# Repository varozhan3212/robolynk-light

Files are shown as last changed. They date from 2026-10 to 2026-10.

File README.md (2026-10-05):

# RoboLynk Light — a talking desk companion on an ESP32-S3

A palm-sized desk robot you hold to talk to. Press the screen, ask a question,
let go — it answers out loud, shows an animated face while it speaks, and can set
alarms and timers or control your smart lights. Everything runs on one
ESP32-S3 board with a 2.8" colour screen, and it updates itself over Wi-Fi.

It is built from an off-the-shelf dev board, so you can reproduce it without a
soldering iron: about ten minutes of hands-on work, plus an hour and twenty
minutes of printing you can leave running.

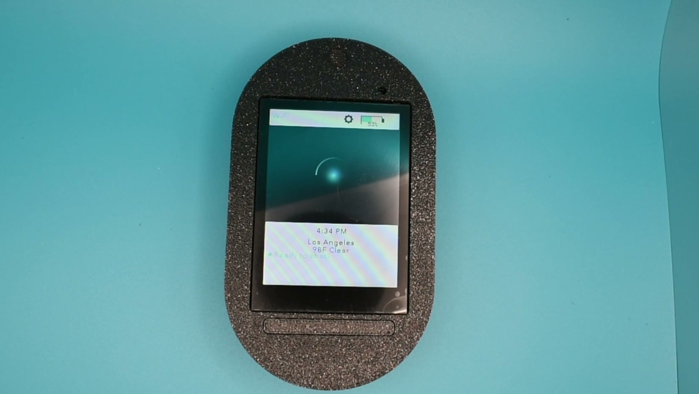
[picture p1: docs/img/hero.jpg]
RoboLynk Lite, assembled and running


---

## What it does

- **Hold-to-talk voice chat.** Press and hold the screen, speak, release. It
  remembers the last six messages, so follow-up questions work.
- **Animated face** while it speaks, drawn from frames held in RAM.
- **Alarms and timers** by voice or from the settings screen.
- **Philips Hue control** — "turn on the lights", "dim the bedroom",
  "lights to 50%".
- **Wi-Fi setup from your phone.** The robot raises its own hotspot and serves a
  small page; you type your network details there. No keyboard needed.
- **Updates itself.** On boot it checks for new firmware and installs it.
- **A light and an SOS signal, both without a network.** Tap the top-left of the
  screen to switch the built-in white LED on and off. Hold it for three seconds and
  it flashes an SOS pattern with an emergency screen. Neither needs Wi-Fi or a
  server, so they work anywhere.
- Optional GPS module for "where am I", and Bluetooth LE scanning. Without a module
  fitted, GPS simply does not appear.

Reminders and alarms here are a convenience feature. Do not rely on them for
anything that matters medically.

**▶ Watch the full build and setup (5 min):** https://youtu.be/vgklh-3mNh4

**📄 Written build guide on Hackster:**
https://www.hackster.io/varozhan/a-talking-desk-robot-you-flash-from-a-web-page-ce6271

Flashing from the browser, Wi-Fi setup from a phone, creating the account,
first boot, and the robot answering a question — start to finish, nothing cut.

---

## Parts

| Part | Notes |
|---|---|
| ES3C28P (or ES3N28P) ESP32-S3 board | [Example on Amazon](https://www.amazon.com/dp/B0FSQLPQ6M) &middot; 2.8" 240×320 ILI9341 display, capacitive touch, ES8311 audio codec, speaker amp, microSD slot, USB-C. **Match the model number** — other ESP32-S3 boards look similar but use a different display controller or have no audio codec, and the firmware will not work on them. |
| microSD card (optional) | Only needed for the higher-frame-count face animation and music. The robot works without one. |
| Speaker | Small 8Ω unit; most of these boards ship with one. |
| GPS module (optional) | UART, 3.3V. Skip unless you want location answers. |
| 3D-printed case | Four printed parts. Confirmed to fit this board. Files below. |
| 630 mAh LiPo battery | 1-cell (3.7 V), JST-PH connector, with a protection circuit. Charges over the board's USB-C. [Example on Amazon](https://www.amazon.com/dp/B0D7MC714N) |
| M2 heat-set inserts x4 | Pressed into the printed shell. [Example kit on Amazon](https://www.amazon.com/dp/B0DRV9R3H9) |
| M2 screws x4 | Secure the case. 6-8 mm suits most prints. Insert kits often include matching screws — check before ordering separately. |
| Hot glue | Holds the board in the shell. |

No custom PCB, and no wiring at all unless you add GPS.

The shopping links are examples, not requirements — listings move and disappear. The model numbers above are what matter, and these parts are widely available from other sellers.

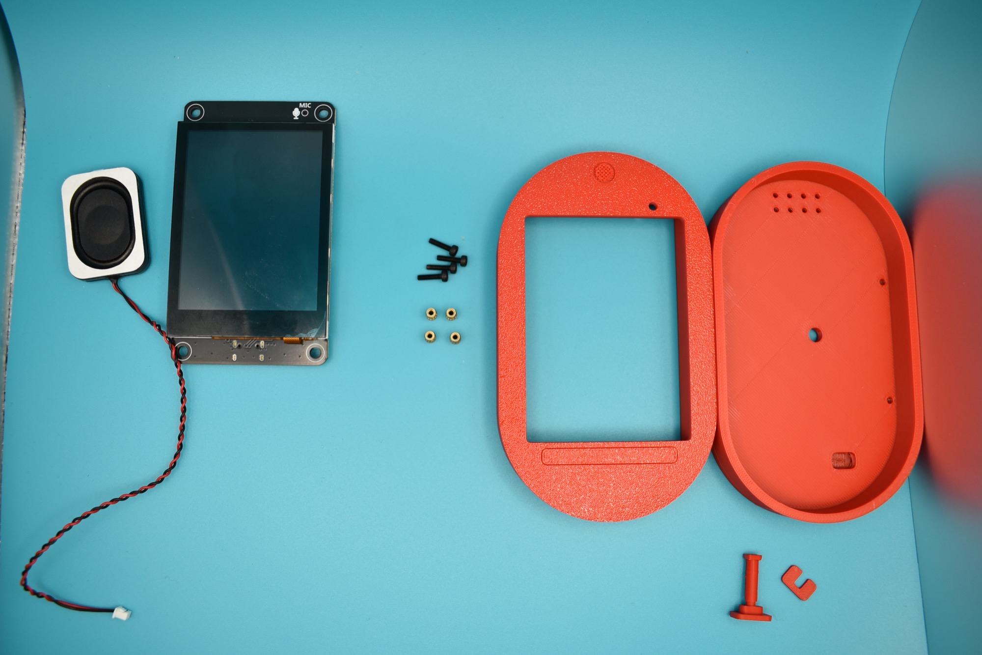
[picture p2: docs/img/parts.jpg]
The parts, laid out


---

## Build

### 1. Flash the firmware

The image contains the runtime, the application and its files in one write.
If you are reflashing a board that has joined a network before, erase it first:
Wi-Fi credentials live in a flash region a plain overwrite leaves behind, so
skipping the erase passes your network password on with the board.

The whole firmware is a single file. **In a browser**, with nothing installed:

1. Open **https://espressif.github.io/esptool-js/** in Chrome or Edge
2. **Connect**, pick the board's serial port
3. Add `robolynk_light_1.3.203.bin`, set the **flash address to `0`**
4. **Program** — about 70 seconds

Or from a terminal, if you prefer:

```bash
esptool --port /dev/cu.usbmodemXXXX write_flash 0x0 robolynk_light_1.3.203.bin
```

**When it finishes, unplug the board and plug it back in.** The flasher reports a
reset, but on this chip that does not actually restart the application — without a
physical replug the screen stays dark and it looks like the flash failed.

### 2. First boot

Power it on. It shows a splash, then **TAP TO BEGIN**.

1. Tap the screen and accept the terms.
2. Choose **Phone Setup**. The robot starts a hotspot called `RoboLynk-XXXX` and
   shows the password on screen.
3. Join that network from your phone, open `192.168.4.1`, pick your Wi-Fi from the
   list and enter the password. Only 2.4 GHz networks appear — the robot cannot use
   5 GHz.
4. The robot saves them, restarts, and connects.
5. Go to **Settings → Info** and note the **Setup Code** (six characters, like
   `GT2-UQK`).
6. On **robolynk.cloud**, create an account, then **Add Robot** → *RoboLynk Lite* and
   enter that code.

Until you add it to an account the robot will say so rather than answering — it is
online, just not linked to anyone yet.

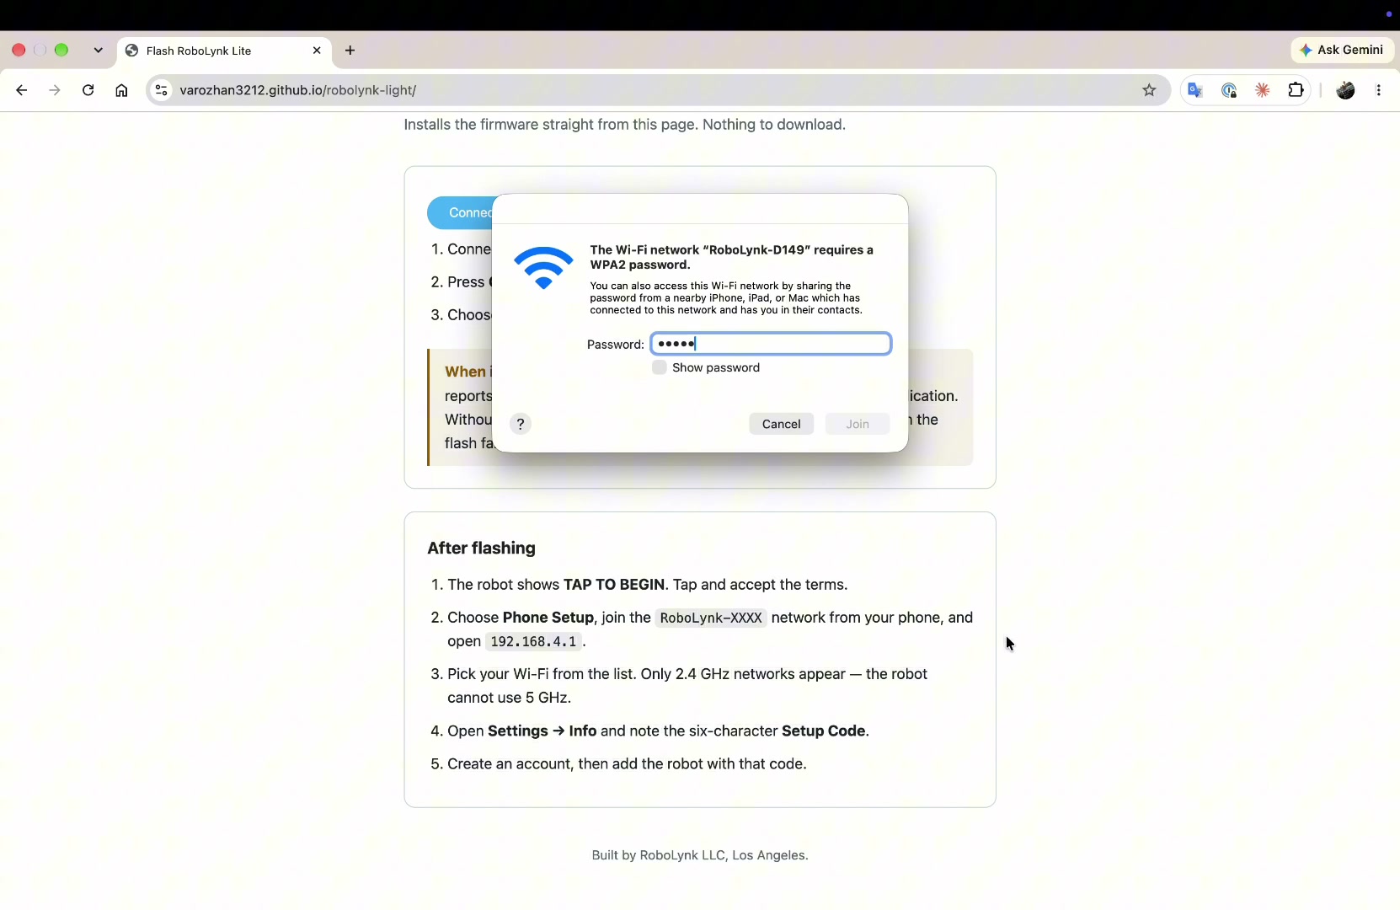
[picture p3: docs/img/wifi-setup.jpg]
Wi-Fi setup page, served by the robot


### 3. Talk to it

Press and hold the screen, ask something, release. There is a few seconds' pause
while it transcribes and thinks, then it speaks the answer.

---

## Enclosure

A four-part printed case, screwed together. Verified against this board.

| Part | Qty | Notes |
|---|---|---|
| `front_shell_v22.stl` | 1 | Holds the display; the screen bezel sits flush |
| `back_cover_v22.stl` | 1 | Closes the rear; USB-C and microSD stay accessible |
| `clips_v22.stl` | 1 plate | Internal clips |
| `buttons_v22.stl` | 1 plate | Caps for the reset and boot buttons |

You also need a glue gun, plus the fasteners listed in Parts.

### Printing

- **Material:** PETG or PLA — both work
- **Layer height:** 0.2 mm
- **Infill:** 20%
- **Supports:** **none needed.** The parts are designed to print unsupported.
- **Orientation:** as the files load on the plate; no reorienting required

Printed on a Bambu Lab with stock profiles. Print the clips and buttons at the same
settings — they are small and fit alongside either shell.

### Assembly

1. **Press the four M2 inserts** into the shell. A soldering iron on low, held
   straight down, seats them cleanly — go slowly and let each one cool.
2. Drop the board into the front shell, display first, and seat the bezel.
3. **Hot-glue the board in place.** It needs it: nothing else stops the board
   shifting, and a loose board puts strain on the USB-C port every time you plug in.
   A few beads at the corners is enough — keep glue off the connectors and clear of
   the battery.
4. Connect the battery and tuck it in so it is not pinched by the shell.
5. Push the button caps into their openings from outside.
6. Fit the back cover and secure with the **four M2 screws**.

### Battery

A single-cell **630 mAh LiPo (3.7 V)** with a JST-PH connector. It charges over the
board's USB-C, so no separate charger is needed.

Check the polarity against your board before plugging it in — JST-PH connectors are
not standardised between suppliers, and a reversed cell will damage the board. If
the housing is wired backwards, move the pins rather than forcing it.

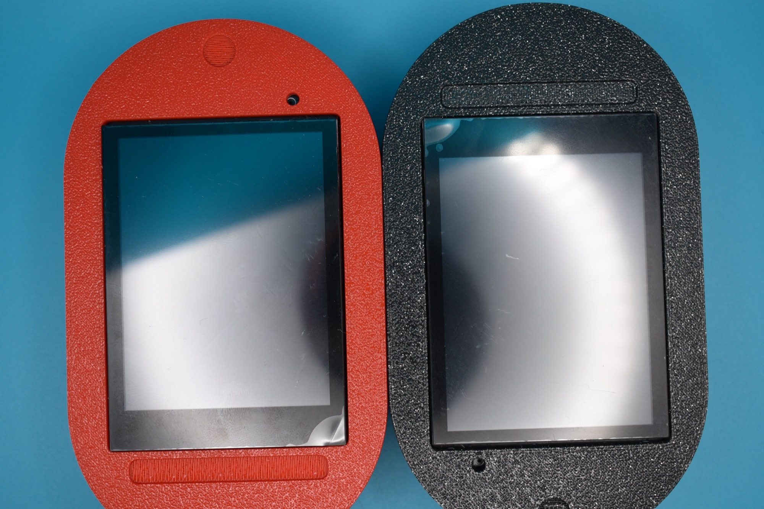
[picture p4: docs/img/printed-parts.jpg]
Printed shells, red and black


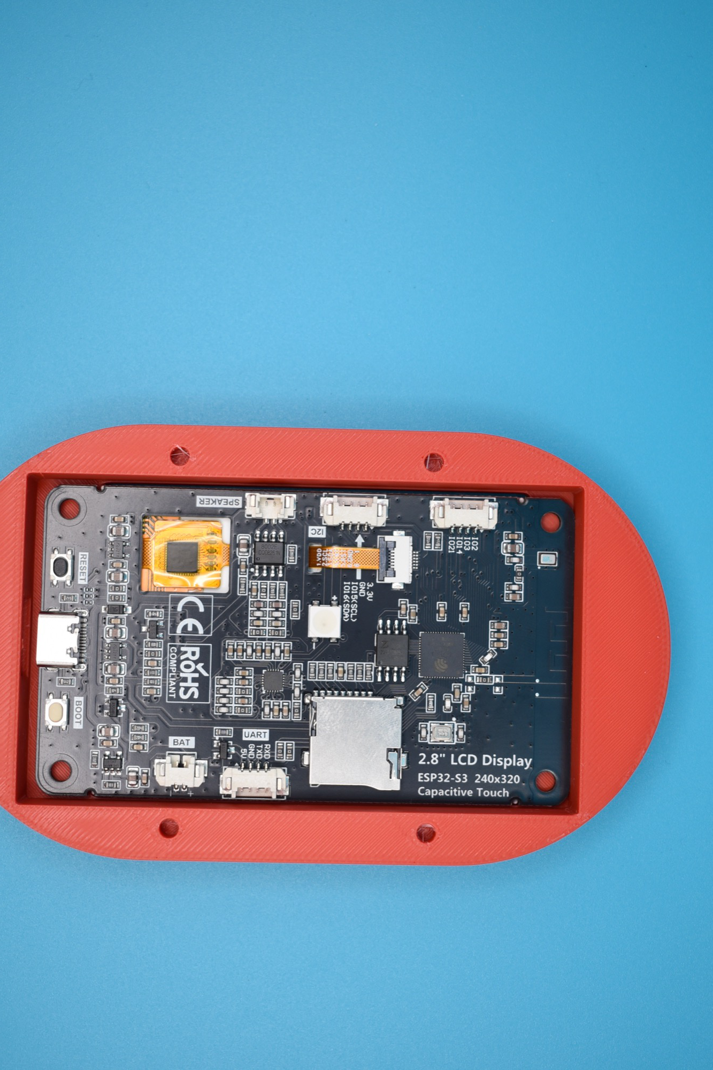
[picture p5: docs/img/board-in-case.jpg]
Board mounted in the case


---

## How it works

Audio is captured through the ES8311 codec over I²S at 16 kHz and streamed to a
server over a WebSocket while you hold the screen. The server transcribes it,
generates a reply, and streams the spoken audio back, which the robot plays while
advancing the face animation between audio writes.

Three things turned out to matter much more than expected:

**Start the microphone before anything else.** The original code updated the
screen and ran a garbage collection before switching the microphone on. Users
start speaking the moment the screen says LISTEN, so the opening word was simply
never recorded — "why is the 4th of July important" arrived as "July is
important". The microphone now starts first and the housekeeping happens behind
it, buffering.

**Don't sip from the audio buffer.** The capture loop read one 30 ms slice per
network send. Each send costs around 110 ms, so it captured barely a quarter of
real time and the rest piled up until the buffer overflowed. Reading until the
buffer is empty, and sending larger batches, fixed it.

**Give streamed audio somewhere to wait.** Playing straight from the network into
a 170 ms hardware buffer means any late packet is an audible gap. Holding ~600 ms
back before starting playback, into a larger buffer, removes it.

None of these were hardware limits. All three looked like one.

---

## Things worth knowing before you build

- **2.4 GHz Wi-Fi only.** No 5 GHz.
- **The face animation is the memory budget.** Frames are held in RAM; the loader
  reserves headroom for the TLS handshake and audio buffers and loads however many
  frames fit. Take that headroom away and it boots to a white screen.
- **A microSD card on a bit-banged SPI bus is slow** — around 93 KB/s here, which
  means a multi-megabyte animation takes over a minute to load at boot. Worth
  planning for if you store large assets.
- **It needs a server.** The speech and language work does not happen on the
  board. This project is the device half.

---

## Licence

Two different things here, under two different terms:

- **The case files, the build guide and the photographs** are
  [CC BY-SA 4.0](https://creativecommons.org/licenses/by-sa/4.0/). Build it,
  print it, change it, sell what you make — credit RoboLynk and share your
  changes under the same terms.
- **The firmware is not open source.** It ships as a binary and is free to use
  on your own device, as many boards as you like. It is not redistributable,
  and the source is not published.

The firmware uses a RoboLynk server for speech and language, so the robot needs
a free account and an internet connection to talk. The lamp, the SOS signal, the
clock and the alarms work without either.

Full terms in [LICENSE](LICENSE).

---

## Status

Working prototype, in daily use. Radio streaming, camera vision and wake-word
detection are present in earlier code but are switched off here — they are not
finished and are not part of this build.

Built by RoboLynk LLC, Los Angeles.

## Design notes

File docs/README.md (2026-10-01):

# GitHub Pages directory

Served at `https://<owner>.github.io/robolynk-light/`.

`manifest.json` points at the firmware **release asset**, not a file in this repo:
a 16 MB binary committed to git stays in history forever. Publish the `.bin` as a
release, then bump the version and URL here.

ESP Web Tools requires HTTPS. GitHub Pages provides it; opening `index.html` from
disk will not work — the install button will report that serial access is blocked.

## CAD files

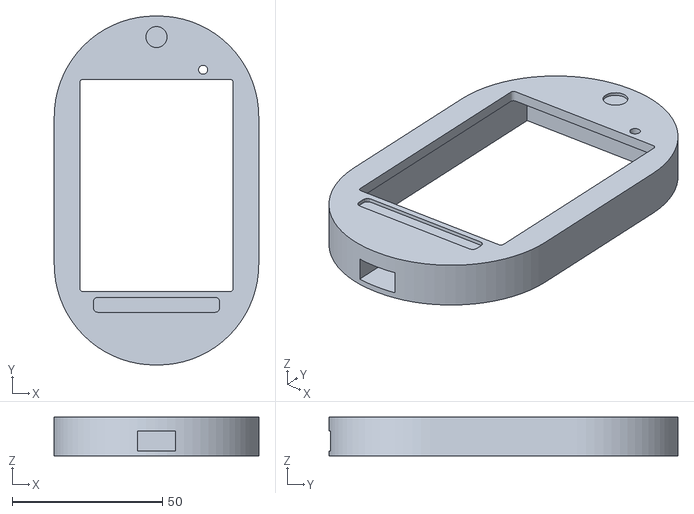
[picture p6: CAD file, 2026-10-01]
case/front_shell_v22.stl
68.0 x 116.0 x 12.9

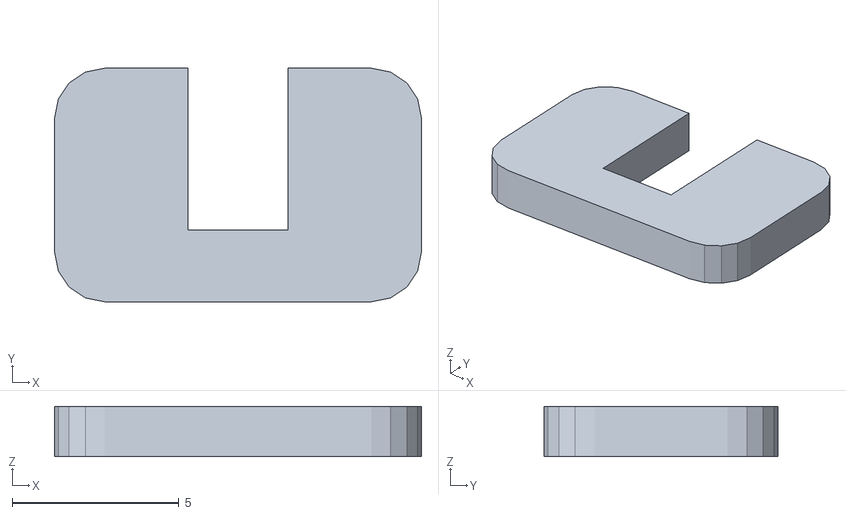
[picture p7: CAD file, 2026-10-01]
case/clips_v22.stl
11.0 x 7.00 x 1.50

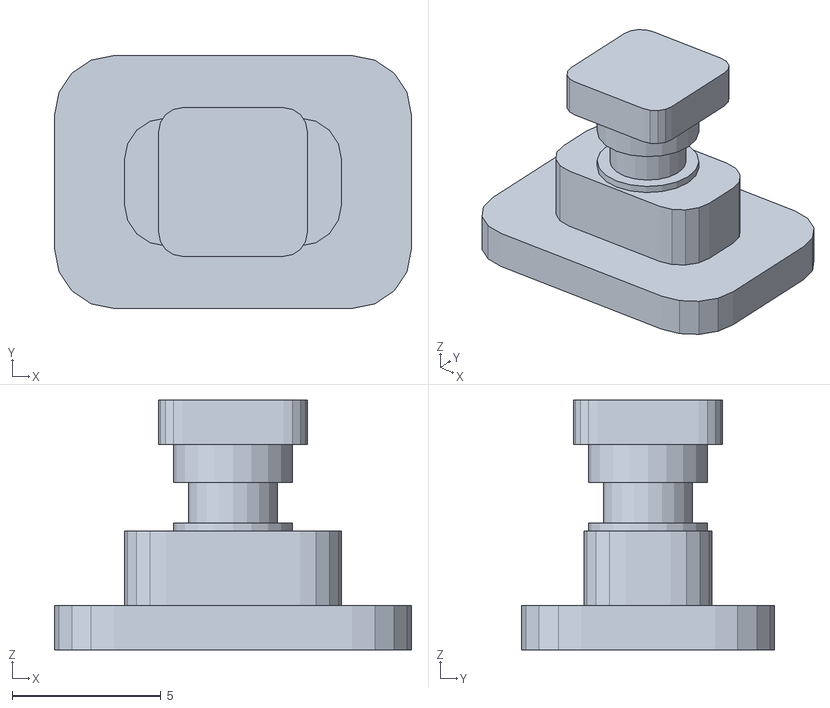
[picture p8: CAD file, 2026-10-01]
case/buttons_v22.stl
12.0 x 8.50 x 8.40

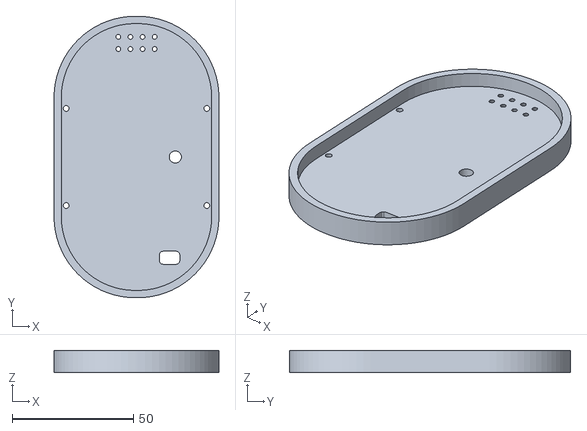
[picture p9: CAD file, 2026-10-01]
case/back_cover_v22.stl
68.0 x 116.0 x 9.10

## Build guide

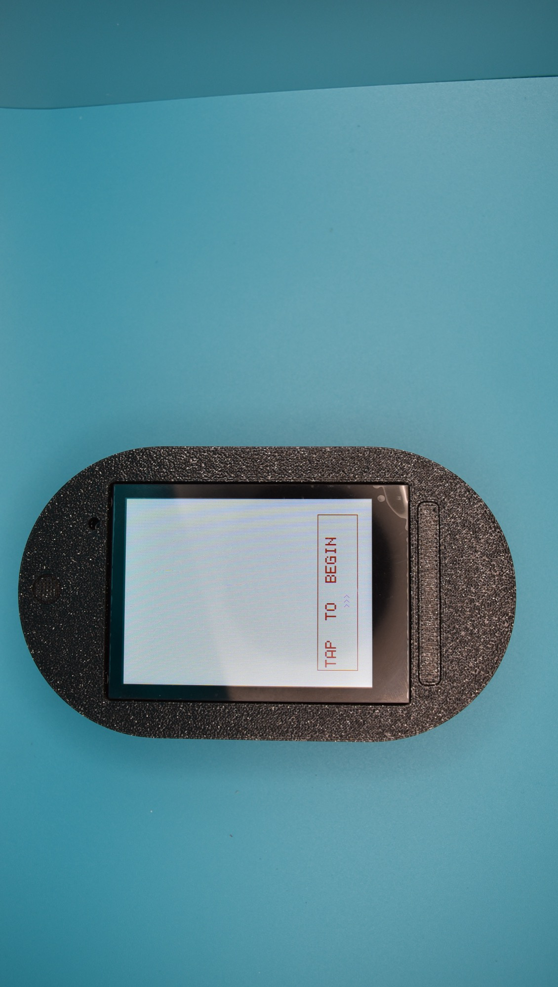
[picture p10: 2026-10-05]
docs/img/assembled.jpg

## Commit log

2026-10-01 RoboLynk Lite: case files, build guide, browser flasher
    [back_cover_v22.stl, buttons_v22.stl, clips_v22.stl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]
2026-10-01 Add example purchase links for the board and battery
2026-10-01 Add example link for the M2 insert and screw kit
2026-10-02 Serve the flash image from robolynk.cloud, not a GitHub release asset
    "Installation failed / Failed to fetch" was CORS. ESP Web Tools reads the
    binary with JavaScript, and GitHub's release-asset host sends no
    Access-Control-Allow-Origin header, so the browser refused the response. curl
    followed the redirect and returned 200, which made the URL look healthy while
    every real install failed -- the browser path had never worked.
    The new endpoint serves the identical bytes (md5 ac176c7b...) with the CORS
    header attached. The GitHub release stays as the archive and for anyone
    flashing with esptool.
2026-10-05 Add the build video and real photographs
    Every placeholder is now a real asset: the hero, the parts, the Wi-Fi setup
    page and the printed shells, plus the full five-minute build and setup video.
    The hero and the Wi-Fi screen are frames pulled from that video rather than
    separate photographs -- the shoot produced flat-lays of the build steps but no
    picture of the finished robot in use, and the video already had the shot.
2026-10-05 State how long the build actually takes
    "An afternoon" was vague and overstated it. Ten minutes hands-on, an hour and
    twenty minutes of printing you can leave running -- which is the first thing a
    reader wants to know before committing.
2026-10-05 Add a licence — the repository had none
    With no LICENSE file every right is reserved by default, which contradicted a
    page inviting people to build and print the thing.
    Two terms, because there are two kinds of content. The case files, guide and
    photographs are CC BY-SA 4.0: build, print, modify, sell what you make, credit
    RoboLynk, share alike. The firmware is a binary, free to use on your own device,
    not redistributable, source not published -- calling that open source would be
    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
